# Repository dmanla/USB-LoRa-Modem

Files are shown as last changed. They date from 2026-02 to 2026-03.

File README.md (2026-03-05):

# USB-LoRa-Modem: Long-Range P2P Terminal

## Overview
**USB-LoRa-Modem** is an open-hardware radio terminal designed to enable any USB-equipped device to communicate over long distances using LoRa modulation. It is optimized for **secure, off-grid text communication** and provides a robust link in environments where cellular or Wi-Fi infrastructure is unavailable.

The core of the device is the **EByte E22-900T30S**, providing high-power **1-Watt (30dBm)** transmission in the US-legal **915MHz** ISM band, with a focus on maximum range and hardware-level signal isolation.

---

## Key Security & Design Features
* **Active-Discharge Kill Switch**: A physical SPDT slide switch (**SW1**) that disconnects the buck converter and actively shorts the internal power rail to ground through a **10Ω** resistor (**R4**). This ensures the **1080µF** bulk capacitance is drained instantly, preventing any residual "heartbeat" transmissions after power-off.
* **EMI & Signal Integrity**: **22Ω** series resistors (**R3, R7**) are placed on the UART data lines (TX, RX). This dampens high-frequency harmonics and limits radiated EMI, ensuring the device remains quiet and the signal remains clean.
* **Hardware Flow Control**: The LoRa module's **AUX** pin is tied to the **CTS** line of the **CH343P**. This allows the host software to automatically manage data buffers, preventing packet loss during high-volume wireless transmissions.
* **High-Current Power Path**: Features a **TPS62A01** synchronous buck converter capable of delivering **1A peak current** to handle the significant power draw of 30dBm LoRa transmissions without voltage brownouts.

---

## Major Components
| Component | Part Number | Description |
| :--- | :--- | :--- |
| **LoRa Module** | **E22-900T30S** | 30dBm (1W) LoRa Transceiver (SX1262 based). |
| **USB-UART Bridge** | **WCH CH343P** | High-speed USB to serial converter with CTS support. |
| **Power Regulator** | **TPS62A01ADRL** | 1000mA Synchronous Buck Converter (5V to 3.3V). |
| **ESD Protection** | **USBLC6-2SC6** | Low-capacitance ESD protection for USB data lines. |

---

## Technical Specifications
* **Input Power**: USB VBUS (+5V, up to 700mA peak).
* **Frequency**: 902–928 MHz (Standard US ISM Band).
* **Range**: ~10km+ Line-of-Sight (Antenna dependent).
* **Logic Level**: 3.3V TTL.
* **EDA Software**: **KiCad 9.0.7**.

---

## Usage
1.  **Enable Device**: Flip **SW1** to the `ON` position.
2.  **Communication**: Open a serial terminal (e.g., `pyserial` or `minicom`) at **9600** baud (default).
3.  **Configuration**: To send **AT Commands**, the device must be in Configuration Mode (Requires M0/M1 pins to be set according to your hardware strapping).
4.  **Kill Session**: Flip **SW1** to the `OFF` position. The power rail is immediately grounded, and the radio is physically silenced.

## Front 3D Render


## Back 3D Render


## License

All PCB design files and hardware are released under the [Creative Commons Attribution Share Alike 4.0](https://choosealicense.com/licenses/cc-by-sa-4.0/) license.

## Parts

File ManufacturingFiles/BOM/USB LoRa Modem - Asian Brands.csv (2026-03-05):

USB LoRa Modem Cost-Optimized BOM
Item # | Designator | Qty | Manufacturer | Mfg Part # | Description / Value | Package/Footprint | Type | Your Instructions / Notes
1 | U7 | 1 | WCH | CH343P | CH343P, USB to UART Bridge | QFN-16-1EP_3x3mm_P0.5mm_EP1.8x1.8mm | SMD | LCSC (C2846043)
2 | U6 | 1 | Texas Instruments | TPS62A01ADRLR | TPS62A01ADRL, Buck Converter 1A | SOT-563 | SMD | LCSC (C2907400)
3 | U4 | 1 | Yenji Elec | USBLC6-2SC6 | USBLC6-2SC6, ESD Protection 2-Line | SOT-23-6 | SMD | LCSC (C323793)
4 | U1 | 1 | EByte | E22-900T30S | E22-900T30S, LoRa Module (1W, 915MHz) | XCVR_E22-900T30S | SMD | EByte Official
5 | SW1 | 1 | G-Switch | G-Switch SK-12F04-G050 | KILL_SWITCH, Slide Switch SPDT | 3-Pin 6mm Angled Switch | SMD | LCSC (C140220)
6 | R6 | 1 | Uniroyal (Uni-Ohm) | 0603WAF7322T5E | 73.2k, Resistor 0.1% 0603 | C_0603_1608Metric_Pad1.08x0.95mm | SMD | LCSC (C14890)
7 | R5 | 1 | Uniroyal (Uni-Ohm) | 0603WAF3303T5E | 330k, Resistor 1% 0603 | C_0603_1608Metric_Pad1.08x0.95mm | SMD | LCSC (C23137)
8 | R4 | 1 | Uniroyal (Uni-Ohm) | 1210WAF100JT5E | 10R, Resistor 1% 1210 | R_1210_3225Metric_Pad1.30x2.65mm | SMD | LCSC (C44451)
9 | R3, R7 | 2 | Uniroyal (Uni-Ohm) | 0603WAF220JT5E | 22R, Resistor 1% 0603 | R_0603_1608Metric_Pad0.98x0.95mm | SMD | LCSC (C23345)
10 | R1, R2 | 2 | FOJAN | FRC0603F1001TS | 1kΩ ±1% 100mW 0603 Thick Film | R_0603_1608Metric_Pad0.98x0.95mm | SMD | LCSC (C2907002)
11 | L1 | 1 | MetalLions | MTQH252012S1R0MBTA | ±20% 6.5A 16mΩ 1uH 5.2A Shielded Inductor | L_1008_2520Metric | SMD | LCSC (C17701215)
12 | J2 | 1 | N/A | N/A | N/A | N/A | SMD | DNP
13 | F1 | 1 | TECHFUSE | nSMD110 | PTC Resettable Fuse 6V 1.1A | Fuse_1206_3216Metric_Pad1.42x1.75mm | SMD | LCSC (C71465)
14 | C17 | 1 | Samsung EM | CL21A226MOQNNNE | 22uF ±20% 16V Ceramic Capacitor X5R 0805 | C_0805_2012Metric | SMD | LCSC (C98190)
15 | C3, C16 | 2 | HRE | CGA0805X5R106K160MT | 10uF ±10% 16V Ceramic Capacitor X5R 0805 | C_0805_2012Metric | SMD | LCSC (C6119886)
16 | C12 | 1 | YAGEO | CC0603JRNPO9BN121 | 120pF, Capacitor 50V C0G 0603 | C_0603_1608Metric_Pad1.08x0.95mm | SMD | LCSC (C107035)
17 | C11 | 1 | Fenghua / Walsin | 0603B104K500CT | 100nF, Capacitor 50V X7R 0603 | C_0603_1608Metric_Pad1.08x0.95mm | SMD | LCSC (C314282)
18 | C4, C10, C13 | 3 | Fenghua / Walsin | 0603B105K500CT | 1uF, Capacitor 50V X7R 0603 | C_0603_1608Metric_Pad1.08x0.95mm | SMD | LCSC (C388003)
19 | C1, C2 | 2 | Kyocera AVX | TAJD477K006RNJ | 470uF, Tantalum Cap 6.3V Case D | CP_EIA-7343-15_Kemet-W | SMD | LCSC (C7229)
20 | J1 | 1 | XUNPU | SMA-KE-347-H13.5-1.6 | CONN RCPT SMA 50Ω SMD | SMA Female Pin 50Ω Surface Mount Offset Pin | SMD | LCSC (C5723200)

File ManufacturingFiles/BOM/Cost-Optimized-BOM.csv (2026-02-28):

Reference | Qty | Value | Description | Manufacturer | Part Number | Distributor | Unit Price (10 Qty) | Total (10 Qty)
U7 | 1 | CH343P | USB to UART Bridge | WCH | CH343P | LCSC (C2846043) | $1.03 | $10.30
U6 | 1 | TPS62A01ADRL | Buck Converter 1A | Texas Instruments | TPS62A01ADRLR | LCSC (C2907400) | $0.13 | $1.30
U4 | 1 | USBLC6-2SC6 | ESD Protection 2-Line | Yenji Elec | USBLC6-2SC6 | LCSC (C323793) | $0.07 | $0.70
U1 | 1 | E22-900T30S | LoRa Module (1W, 915MHz) | EByte | E22-900T30S | EByte Official | $8.90 | $89.00
SW1 | 1 | KILL_SWITCH | Slide Switch SPDT | XKB Connectivity | SS-12D00G5 | LCSC (C140220) | $0.15 | $1.50
R6 | 1 | 73.2k | Resistor 0.1% 0603 | Uniroyal (Uni-Ohm) | 0603WAF7322T5E | LCSC | $0.02 | $0.20
R5 | 1 | 330k | Resistor 1% 0603 | Uniroyal (Uni-Ohm) | 0603WAF3303T5E | LCSC | $0.01 | $0.10
R4 | 1 | 10R | Resistor 1% 1210 | Uniroyal (Uni-Ohm) | 1210WAF100JT5E | LCSC | $0.03 | $0.30
R3, R7 | 2 | 22R | Resistor 1% 0603 | Uniroyal (Uni-Ohm) | 0603WAF220JT5E | LCSC | $0.01 | $0.20
R1, R2 | 2 | 1k | Resistor 1% 0603 | Uniroyal (Uni-Ohm) | 0603WAF1001T5E | LCSC | $0.01 | $0.20
L1 | 1 | 1uH | Inductor 1A 1210 | Sunlord | MWSA0402-1R0MT | LCSC (C28172) | $0.15 | $1.50
J2 | 1 | USB_JUMPER | Pin Header 1x4 2.54mm | Uniroyal (Uni-Ohm) |  | LCSC | $0.05 | $0.50
F1 | 1 | PTC_FUSE | PTC Fuse 1.1A Hold 1206 | Polyfuse | 1206L110SL | LCSC (C41893) | $0.05 | $0.50
C17 | 1 | 22uF | Capacitor 10V X5R 0805 | Fenghua / Walsin | 0805B226K100CT | LCSC | $0.03 | $0.30
C16 | 1 | 10uF | Capacitor 10V X5R 0805 | Fenghua / Walsin | 0805B106K100CT | LCSC | $0.02 | $0.20
C12 | 1 | 120pF | Capacitor 50V C0G 0603 | Fenghua / Walsin | 0603N121J500CT | LCSC | $0.01 | $0.10
C11 | 1 | 100nF | Capacitor 50V X7R 0603 | Fenghua / Walsin | 0603B104K500CT | LCSC | $0.01 | $0.10
C4, C10, C13 | 3 | 1uF | Capacitor 50V X7R 0603 | Fenghua / Walsin | 0603B105K500CT | LCSC | $0.01 | $0.30
C3 | 1 | 10uF | Capacitor 10V X5R 0603 | Fenghua / Walsin | 0805B106K100CT | LCSC | $0.02 | $0.20
C1, C2 | 2 | 470uF | Tantalum Cap 6.3V Case D | Kyocera AVX | TAJD477K006RNJ | LCSC (C7229) | $0.86 | $17.20

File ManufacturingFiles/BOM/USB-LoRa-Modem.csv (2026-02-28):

Reference | Qty | Value | Description | Manufacturer | Part Number | Distributor | Unit Price (10 Qty) | Total (10 Qty)
U7 | 1 | CH343P | USB to UART Bridge | WCH | CH343P | DigiKey | $1.03 | $10.30
U6 | 1 | TPS62A01ADRL | Buck Converter 1A | Texas Instruments | TPS62A01ADRLR | DigiKey | $0.13 | $1.30
U4 | 1 | USBLC6-2SC6 | ESD Protection 2-Line | STMicroelectronics | USBLC6-2SC6 | DigiKey | $0.24 | $2.40
U1 | 1 | E22-900T30S | LoRa Module (1W, 915MHz) | EByte | E22-900T30S | DigiKey | $11.30 | $113.00
SW1 | 1 | KILL_SWITCH | Slide Switch SPDT | C&K | OS102011MA1Q | DigiKey | $0.54 | $5.40
R6 | 1 | 73.2k | Resistor 0.1% 0603 | Yageo | RC0603FR-0773K2L | DigiKey | $0.10 | $1.00
R5 | 1 | 330k | Resistor 1% 0603 | Yageo | RC0603FR-07330KL | DigiKey | $0.05 | $0.50
R4 | 1 | 10R | Resistor 1% 1210 | Yageo | RC1210FR-0710RL | DigiKey | $0.08 | $0.80
R3, R7 | 2 | 22R | Resistor 1% 0603 | Yageo | RC0603FR-0722RL | DigiKey | $0.05 | $1.00
R1, R2 | 2 | 1k | Resistor 1% 0603 | Yageo | RC0603FR-071KL | DigiKey | $0.05 | $1.00
L1 | 1 | 1uH | Inductor 1A 1210 | Wurth | 74404031010 | DigiKey | $0.45 | $4.50
J2 | 1 | USB_JUMPER | Pin Header 1x4 2.54mm | Yageo |  | DigiKey | $0.25 | $2.50
F1 | 1 | PTC_FUSE | PTC Fuse 1.1A Hold 1206 | Bourns | MF-MSMF110-2 | DigiKey | $0.35 | $3.50
C17 | 1 | 22uF | Capacitor 10V X5R 0805 | Samsung | CL21A226MPQNNNE | DigiKey | $0.08 | $0.80
C16 | 1 | 10uF | Capacitor 10V X5R 0805 | Samsung | CL21A106KPCLQNC | DigiKey | $0.05 | $0.50
C12 | 1 | 120pF | Capacitor 50V C0G 0603 | Samsung | CL10C121JB8NNNC | DigiKey | $0.03 | $0.30
C11 | 1 | 100nF | Capacitor 50V X7R 0603 | Samsung | CL10B104KB8NNNC | DigiKey | $0.02 | $0.20
C4, C10, C13 | 3 | 1uF | Capacitor 50V X7R 0603 | Samsung | CL10B105KA8NNNC | DigiKey | $0.03 | $0.90
C3 | 1 | 10uF | Capacitor 10V X5R 0603 | Samsung | CL10A106KP8NNNC | DigiKey | $0.05 | $0.50
C1, C2 | 2 | 470uF | Tantalum Cap 6.3V Case D | Kyocera AVX | TAJD477K006RNJ | DigiKey | $1.45 | $29.00

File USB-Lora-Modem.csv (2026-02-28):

Reference | Qty | Value/Description | Footprint | Manufacturer | Part Number | Unit Price (10 Qty) | Total (10 Qty)
U2 | 1 | Cellular Module Cat-M/NB-IoT | LCC-80 (17.6x15.7mm) | SimCom | SIM7080G | $19.72 | $197.20
U3 | 1 | eSIM IC GSMA | VFDFPN8 (2x3mm) | STMicroelectronics | ST4SIM-200M | $3.00 | $30.00
U7 | 1 | USB to UART Bridge | QFN-16 (3x3mm) | WCH | CH343P | $1.03 | $10.30
U6 | 1 | Buck Converter 1A | SOT-563 | Texas Instruments | TPS62A01ADRLR | $0.13 | $1.30
U1,U4 | 2 | ESD Protection 2-Line | SOT-23-6 | STMicroelectronics | USBLC6-2SC6 | $0.24 | $4.80
D2 | 1 | TVS Diode Array 5-Line | SOT-353 (SC-70-5) | STMicroelectronics | ESDA6V1W5 | $0.24 | $2.40
C1,C18 | 2 | 470uF 6.3V Tantalum Case D | 2917 (7343 Metric) | Vishay / Sprague | TR3D477M6R3C0200 | $1.45 | $29.00
J1 | 1 | U.FL Connector | U.FL (SMT) | Hirose | U.FL-R-SMT-1(10) | $1.10 | $11.00
J3 | 1 | USB Micro-B Connector | USB Micro-B (SMT) | XKB Connectivity | U254-051T-4BH83-F1S | $0.13 | $1.30
J4 | 1 | Nano SIM Connector Hinged | Nano-SIM (SMT) | CUI Devices | NSIM-2-C | $0.55 | $5.50
SW1 | 1 | Slide Switch SPDT | SPDT Right Angle | C&K | OS102011MA1Q | $0.54 | $5.40
F1 | 1 | PTC Fuse 1.1A Hold | 1206 (3216 Metric) | Bel Fuse | 0ZCJ0110FF2E | $0.22 | $2.20
L1 | 1 | Inductor 1uH 1A | 1210 (3225 Metric) | Murata | LQH32CN1R0M33L | $0.08 | $0.80
Q1,Q2,Q3 | 3 | Digital Transistor NPN | SOT-323 (SC-70) | Rohm Semiconductor | DTC143ZUA | $0.23 | $6.90
D3 | 1 | LED Blue (NETLIGHT) | 0603 (1608 Metric) | Lite-On | LTST-C190TBKT | $0.10 | $1.00
D4 | 1 | LED Red (STATUS) | 0603 (1608 Metric) | Lite-On | LTST-C190KRKT | $0.10 | $1.00
C4,C5 | 2 | 100uF 6.3V X5R | 1206 (3216 Metric) | Samsung | CL31A107MQHNNNE | $0.20 | $4.00
C17 | 1 | 22uF 10V X5R | 0805 (2012 Metric) | Samsung | CL21A226MPQNNNE | $0.10 | $1.00
C16 | 1 | 10uF 10V X5R | 0805 (2012 Metric) | Samsung | CL21A106KPCLQNC | $0.05 | $0.50
C6,C10,C13 | 3 | 1uF 16V X7R | 0603 (1608 Metric) | Yageo | CC0603KRX7R7BB105 | $0.02 | $0.60
C11 | 1 | 100nF 16V X7R | 0603 (1608 Metric) | Yageo | CC0603KRX7R7BB104 | $0.01 | $0.10
C7,C8,

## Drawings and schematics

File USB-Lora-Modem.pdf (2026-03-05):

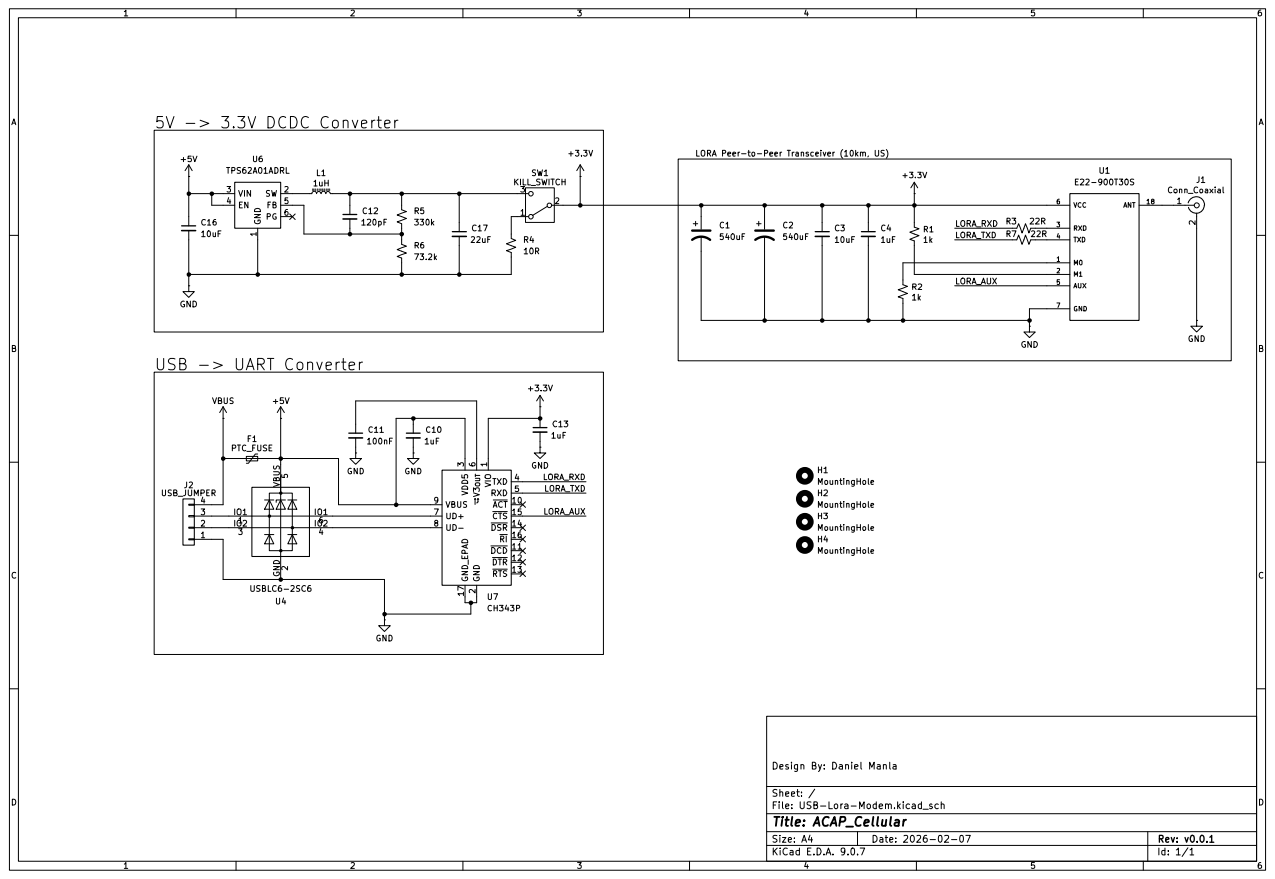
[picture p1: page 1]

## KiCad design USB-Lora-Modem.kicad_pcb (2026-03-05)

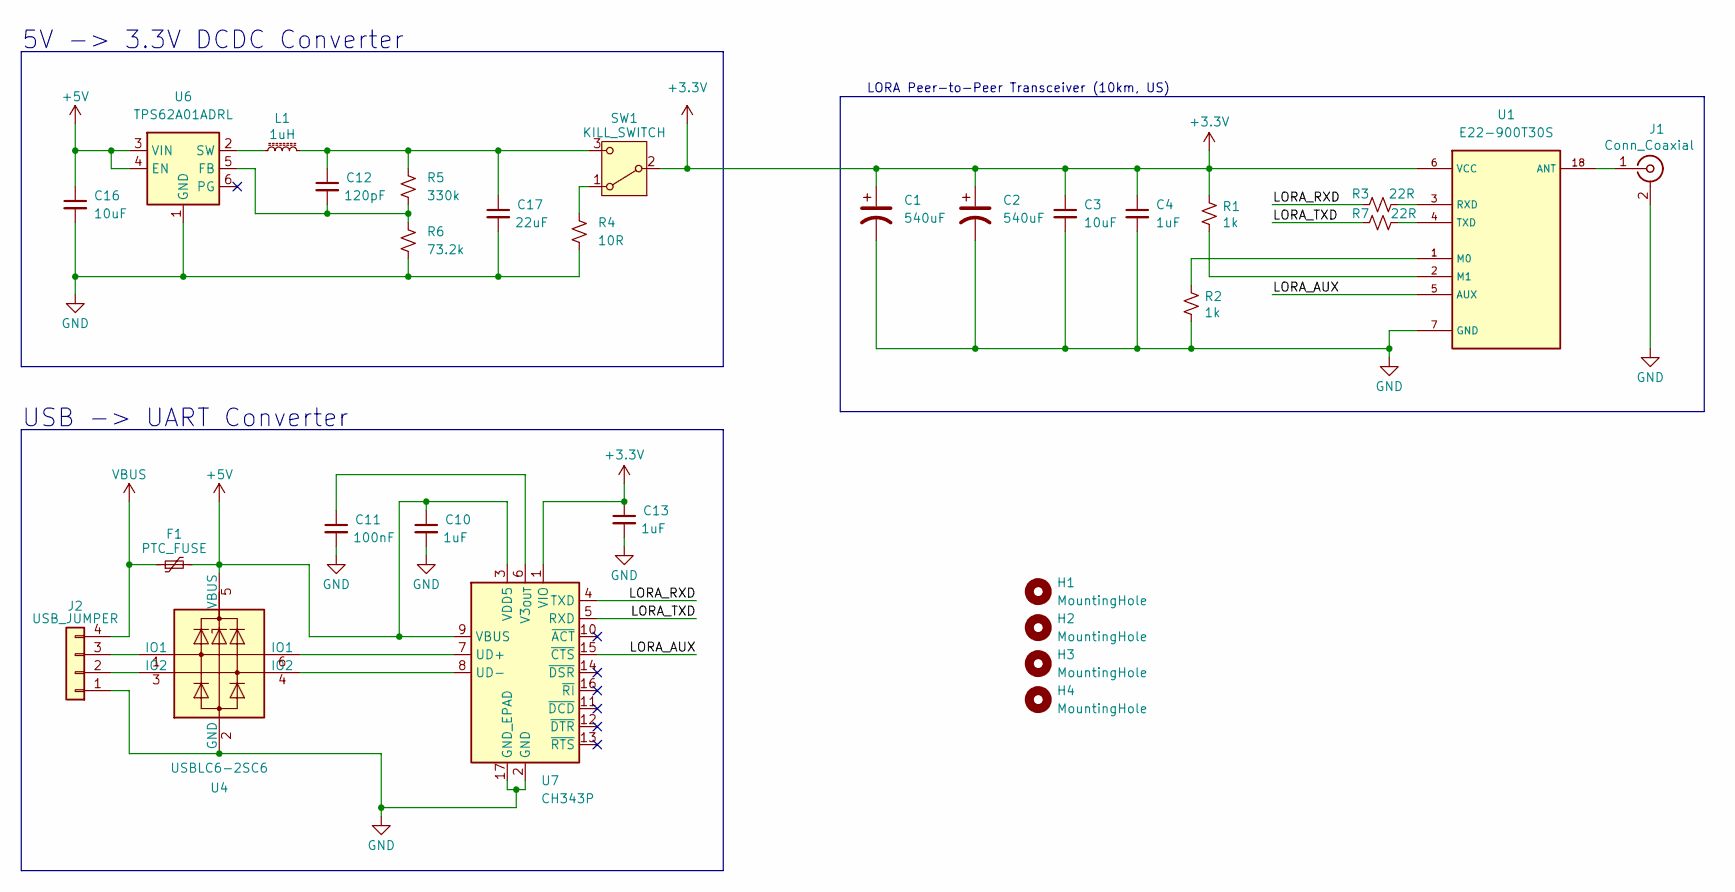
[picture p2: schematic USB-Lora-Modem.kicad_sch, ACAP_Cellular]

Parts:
C1, C2: 540uF; CP_EIA-7343-15_Kemet-W
C3: 10uF; C_0805_2012Metric_Pad1.18x1.45mm_HandSolder
C4, C10, C13: 1uF; C_0603_1608Metric_Pad1.08x0.95mm_HandSolder
C11: 100nF; C_0603_1608Metric_Pad1.08x0.95mm_HandSolder
C12: 120pF; C_0603_1608Metric_Pad1.08x0.95mm_HandSolder
C16: 10uF; C_0805_2012Metric
C17: 22uF; C_0805_2012Metric
F1: PTC_FUSE; Fuse_1206_3216Metric_Pad1.42x1.75mm_HandSolder
H1, H2, H3, H4: MountingHole; MountingHole_3.2mm_M3
J1: Conn_Coaxial; SMA_Amphenol_132289_EdgeMount
J2: USB_JUMPER; PinHeader_1x04_P2.54mm_Vertical
L1: 1uH; L_1210_3225Metric_Pad1.42x2.65mm_HandSolder
R1, R2: 1k; R_0603_1608Metric_Pad0.98x0.95mm_HandSolder
R3, R7: 22R; R_0603_1608Metric_Pad0.98x0.95mm_HandSolder
R4: 10R; R_1210_3225Metric_Pad1.30x2.65mm_HandSolder
R5: 330k; C_0603_1608Metric_Pad1.08x0.95mm_HandSolder
R6: 73.2k; C_0603_1608Metric_Pad1.08x0.95mm_HandSolder
SW1: KILL_SWITCH; SK-12F04-G050
U1: E22-900T30S; XCVR_E22-900T30S
U4: USBLC6-2SC6; SOT-23-6_Handsoldering
U6: TPS62A01ADRL; SOT-563
U7: CH343P; WCH_QFN-16-1EP_3x3mm_P0.5mm_EP1.8x1.8mm

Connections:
+3.3V: C1.1, C2.1, C3.1, C4.1, C13.1, R1.1, SW1.2 (B), U1.6 (VCC), U7.1 (VIO)
+5V: C10.1, C16.1, F1.2, U4.5 (VBUS), U6.3 (VIN), U6.4 (EN), U7.3 (VDD5), U7.9 (VBUS)
/LORA_AUX: U1.5 (AUX), U7.15 (~CTS)
/LORA_RXD: R3.1, U7.4 (TXD)
/LORA_TXD: R7.1, U7.5 (RXD)
GND: C1.2, C2.2, C3.2, C4.2, C10.2, C11.2, C13.2, C16.2, C17.2, J1.2 (Ext), J2.1, R2.2, R4.2, R6.2, U1.7 (GND), U1.9 (GND), U1.15 (GND), U1.16 (GND), U1.17 (GND), U4.2 (GND), U6.1 (GND), U7.2 (GND), U7.17 (GND_EPAD)
unnamed: J1.1 (In), U1.18 (ANT)
unnamed: J2.2, U4.3 (IO2)
unnamed: J2.3, U4.1 (IO1)
unnamed: R4.1, SW1.1 (A)
unnamed: C12.1, C17.1, L1.2, R5.1, SW1.3 (C)
unnamed: R2.1, U1.1 (M0)
unnamed: R1.2, U1.2 (M1)
unnamed: R3.2, U1.3 (RXD)
unnamed: R7.2, U1.4 (TXD)
unnamed: C12.2, R5.2, R6.1, U6.5 (FB)
unnamed: L1.1, U6.2 (SW)
unnamed: U4.6 (IO1), U7.7 (UD+)
unnamed: U4.4 (IO2), U7.8 (UD-)
unnamed: C11.1, U7.6 (V3_{OUT})
VBUS: F1.1, J2.4

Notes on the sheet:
LORA Peer-to-Peer Transceiver (10km, US)
5V -> 3.3V DCDC Converter
USB -> UART Converter

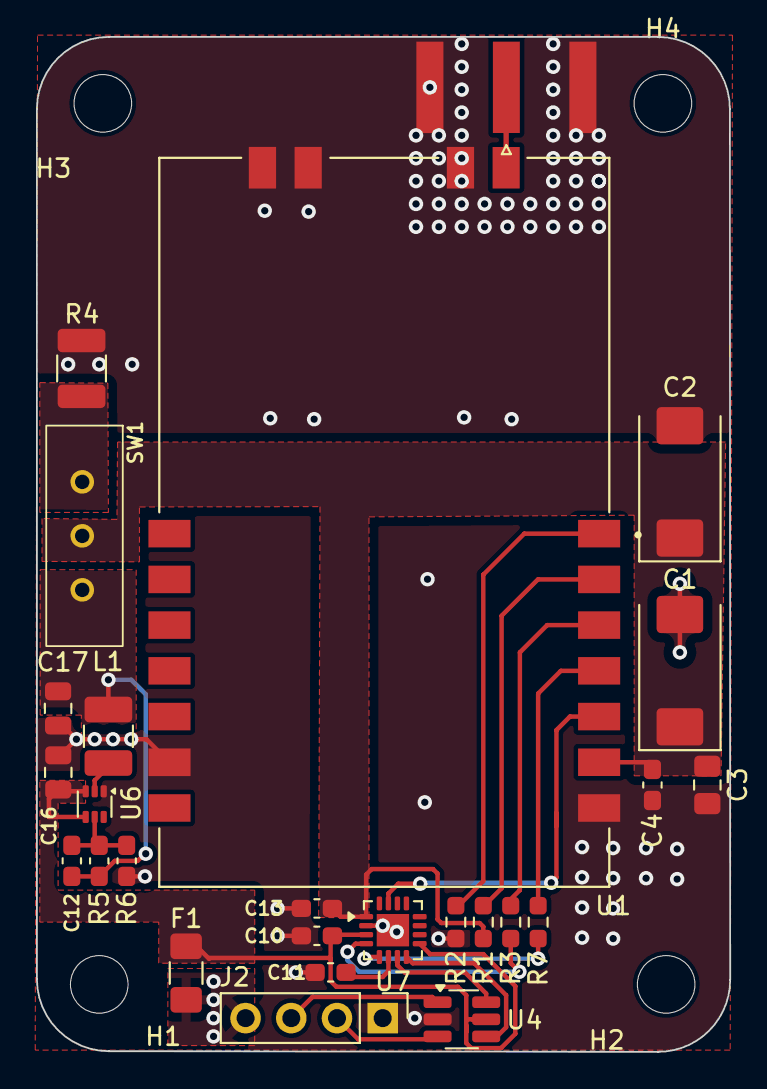
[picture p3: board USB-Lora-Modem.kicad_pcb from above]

Board: 4 copper layers, 38.5 x 56.4 mm, 30 parts (0 on the bottom side), 21 nets.

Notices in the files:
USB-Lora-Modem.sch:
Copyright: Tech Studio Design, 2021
